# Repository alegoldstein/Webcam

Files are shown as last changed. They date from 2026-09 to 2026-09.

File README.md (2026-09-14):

# Webcam
Objective:
Create a webcam from scratch, including PCB, firmware, and enclosure

Steps Taken:
- Used KiCAD to design a compact 50 mm × 50 mm custom PCB integrating a microcontroller, ESP32 module, camera interface,  input buttons, status LEDs, power regulation circuitry, and passive components.
- Developed embedded firmware in Microchip Studio to enable controlled image capture and system-level communication.
- Implemented multiple communication protocols, including UART and SPI for MCU–ESP32 data exchange and debugging, and  I²C for camera initialization.
- Designed a 3D printed enclosure providing access to buttons and power, visibility for indicator LEDs, and support for wall mounting.

Outcome:
A functional webcam that streams images to the web when there is a connected client.

<p align="center">
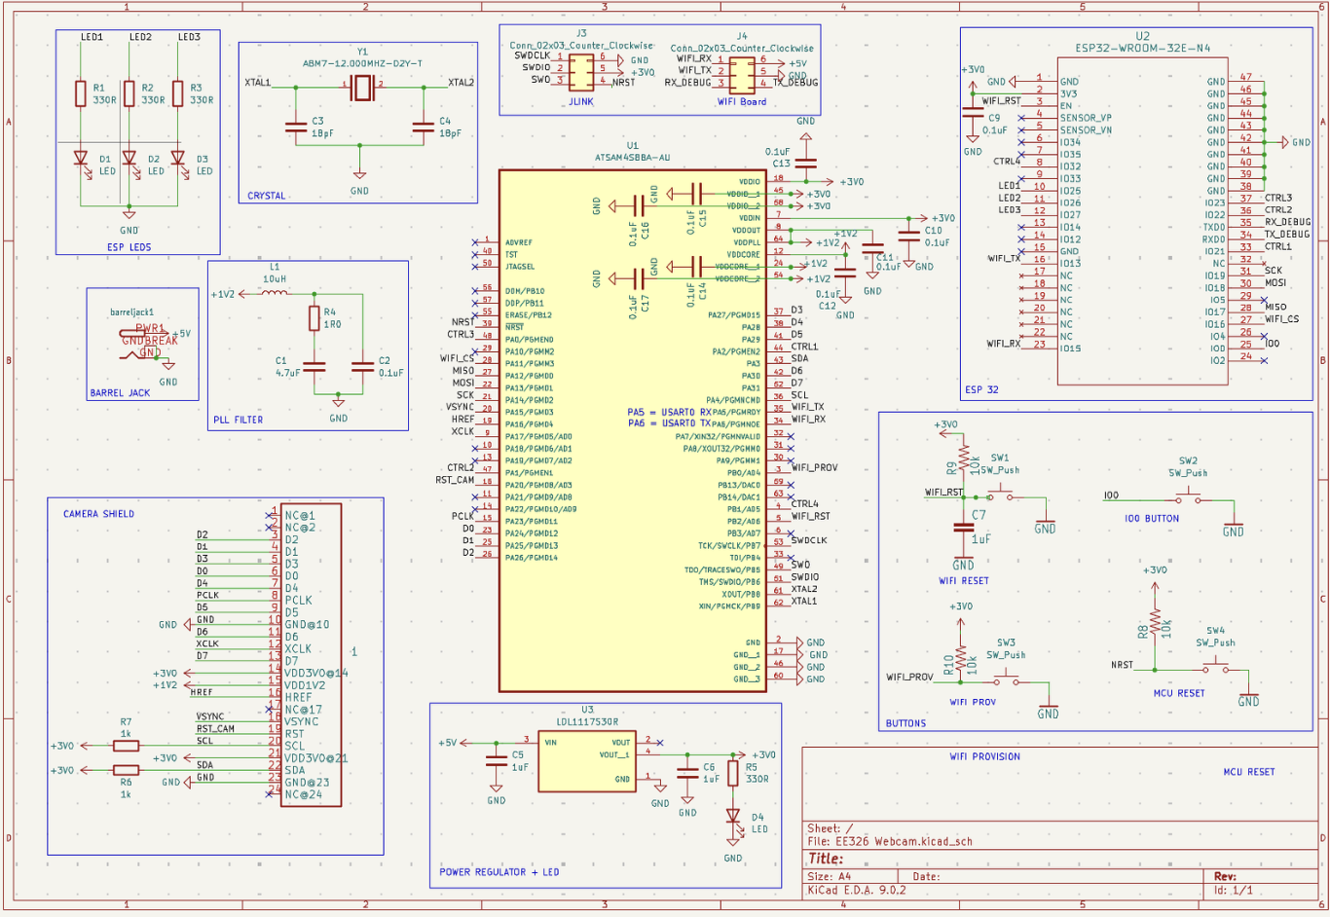
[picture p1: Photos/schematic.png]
  
  <br>
  <em>PCB Schematic</em>
</p>

<p align="center">
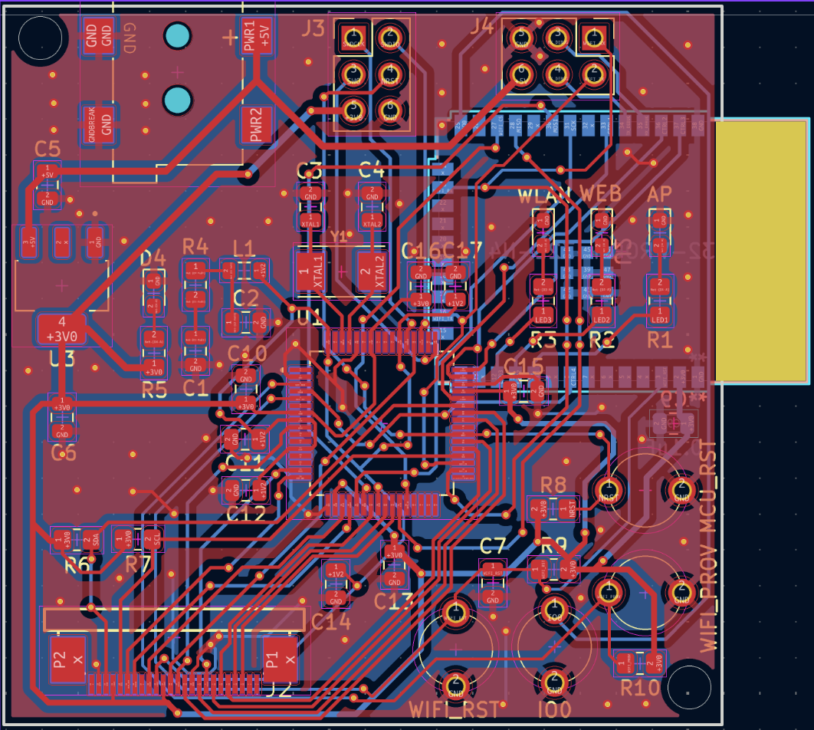
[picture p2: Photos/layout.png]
  
  <br>
  <em>Routing of PCB</em>
</p>

<table align="center">
  <tr>
    <td align="center">
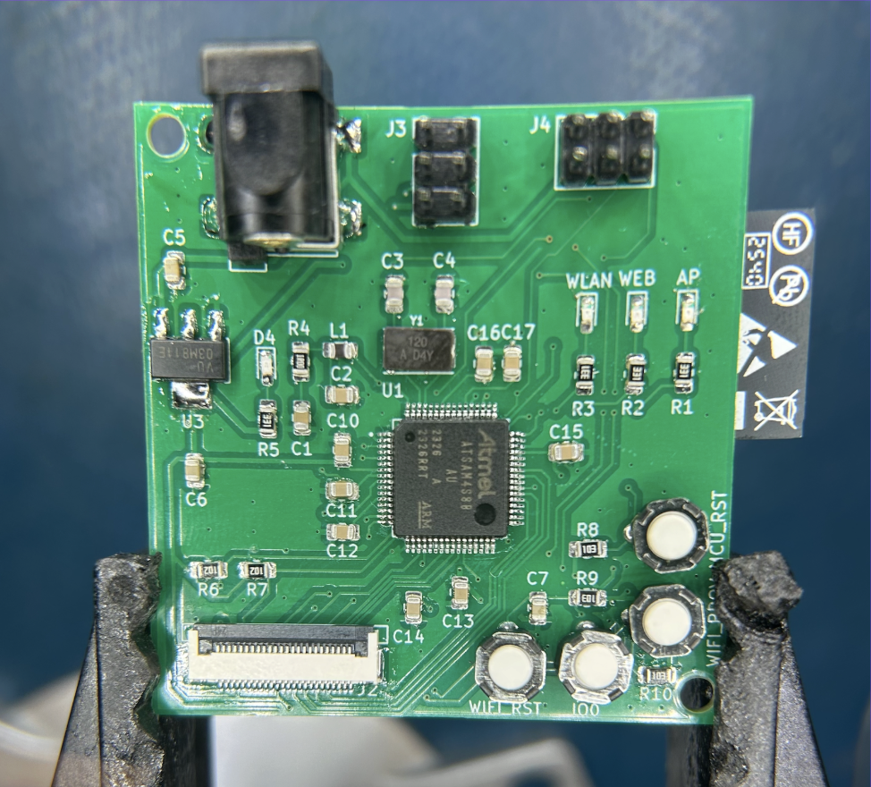
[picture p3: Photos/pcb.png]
      <br>
      <em>Assembled PCB (hand soldered)</em>
    </td>
    <td align="center">
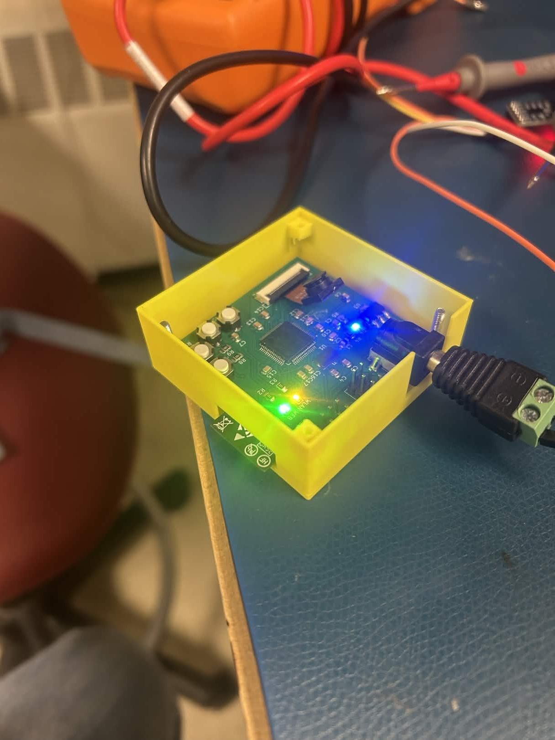
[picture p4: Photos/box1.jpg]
      <br>
      <em>PCB inside of 3D printed box</em>
    </td>
    <td align="center">
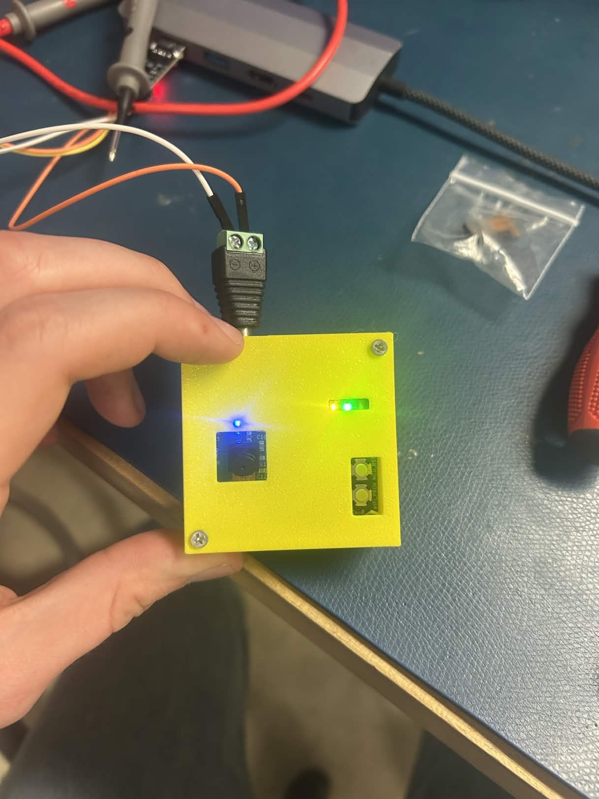
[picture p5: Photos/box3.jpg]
      <br>
      <em>Final product</em>
    </td>
  </tr>
</table>

<p align="center">
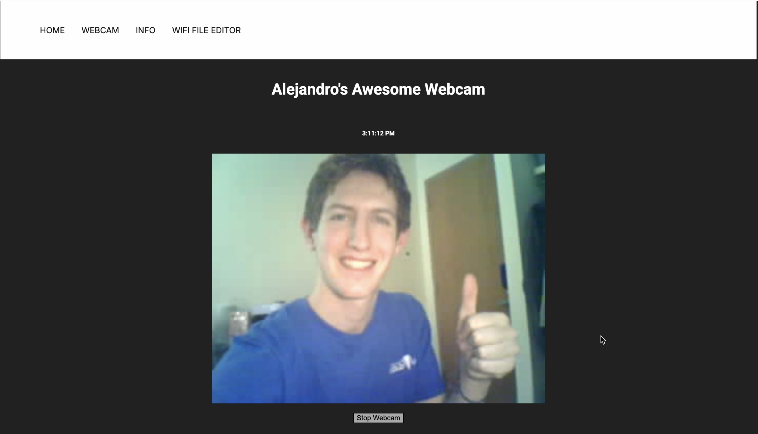
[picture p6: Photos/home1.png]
  
  <br>
  <em>Live streaming of webcam to website</em>
</p>

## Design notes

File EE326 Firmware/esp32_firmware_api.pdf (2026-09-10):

### EE 326: Electronic System Design 1

## WiFi Module API

Firmware version 1.0

This document describes the UART API for the WiFi module firmware. All commands issued must end with a carriage return and a newline character. The Response specification indicates what is returned to the MCU UART, not the debugging UART. The debugging UART may show more information. Any invalid command will get a response of “invalid command” to both the MCU UART and the debugging UART.

## 1 System

- Perform UART test.
– Command: test
– Action: None
– Response: SUCCESS
- Get firmware version.
– Command: ver
– Action: Prints <VERSION NUMBER> to the debugging UART. – Response: None
- Get MAC address of ESP32.
– Command: get mac
– Action: Prints MAC address to debugging UART. – Response: None
- Set SPI baud rate.
– Command: set spi baud <BAUD RATE>
– Action: Set SPI baud rate to <BAUD RATE>.
– Response: None
- Transfer image.
– Command: image transfer <LENGTH IN BYTES>
– Action: Activate controller SPI transfer of <LENGTH IN BYTES> bytes. Make sure the peripheral is ready for transfer.
– Response: None
- Start WiFi provisioning mode on ESP32.
– Command: provision
– Action: Starts provisioning mode on ESP32. This configures the ESP32 as an access point with SSID “ESD1 XY”, where X is the fifth byte of the MAC address and Y is the sixth byte of the MAC address. When you connect to this access point, you will be taken to a captive portal that will allow you to configure your network. When provisioning is complete, the ESP32 will boot into its normal mode of operation.
– Response: None

1

## 2 GPIOs

- Configure network GPIO.
– Command: set net gpio <PIN NUM>
– Action: Set the pin indicated by <PIN NUM> to indicate whether the ESP32 is connected to the internet. If there is a connection, the pin outputs HIGH. Otherwise, it outputs LOW. – Response: None
- Configure websocket clients GPIO.
– Command: set clients gpio <PIN NUM>
– Action: Set the pin indicated by <PIN NUM> to indicate whether any clients are connected to the websockets server hosted by the ESP32, indicating that someone is watching the video stream. If any clients are connected, the pin outputs HIGH. Otherwise, it outputs LOW.
– Response: None
- Configure command complete GPIO.
– Command: set comm gpio <PIN NUM>
– Action: Set the pin indicated by <PIN NUM> to indicate when an API command has finished being received and processed. At the start of processing, this pin goes LOW. When processing is complete, this pin goes HIGH. Therefore, the MCU can sense the rising edge to indicate when it is safe to proceed to the next command.
– Response: None

## 3 Indicators (LEDs)

- Configure network indicator.
– Command: set wlan gpio <PIN NUM>
– Action: Set the pin indicated by <PIN NUM> to indicate the status of the network connection. Short blinks (125ms) indicate no connection. Long blinks (1s) indicate a connection. If <PIN NUM> is specified as “off”, then the indicator is disabled.
– Response: None
- Configure websocket connection indicator.
– Command: set websocket gpio <PIN NUM>
– Action: Set the pin indicated by <PIN NUM> to indicate the status of the websockets connections (i.e. whether clients are connected or not). Short blinks (125ms) indicate no connections. Long blinks (1s) indicate at least one connection. If <PIN NUM> is specified as “off”, then the indicator is disabled.
– Response: None
- Configure provisioning indicator.
– Command: set ap gpio <PIN NUM>
– Action: Set the pin indicated by <PIN NUM> to indicate the status of provisioning mode. Short blinks (125ms) indicate that provisioning mode is active but no clients have connected to the access point. Long blinks (1s) indicate that provisioning mode is active an a client has connected to the access point. When provisioning is complete, the indicator turns off. If <PIN NUM> is specified as “off”, then the indicator is disabled.
– Response: None

2

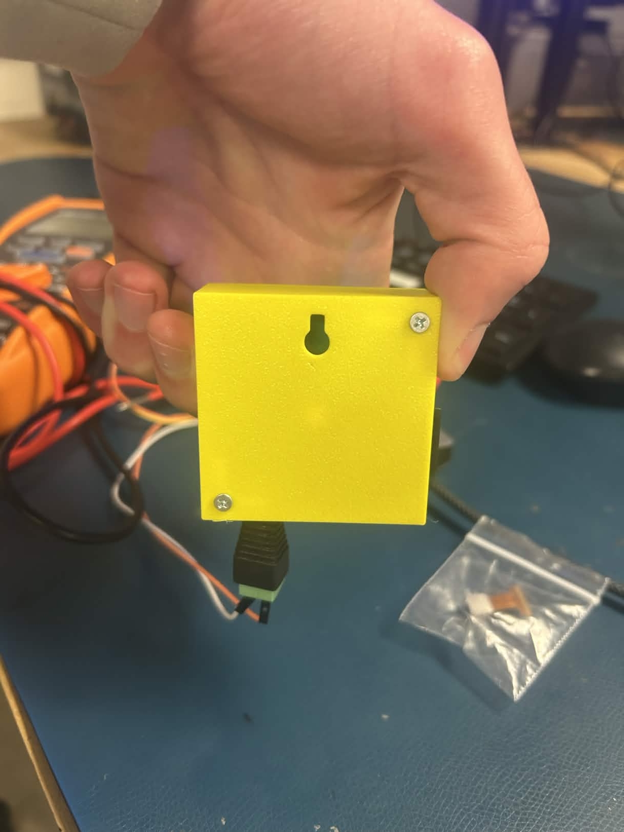
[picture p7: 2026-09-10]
Photos/box2.jpg

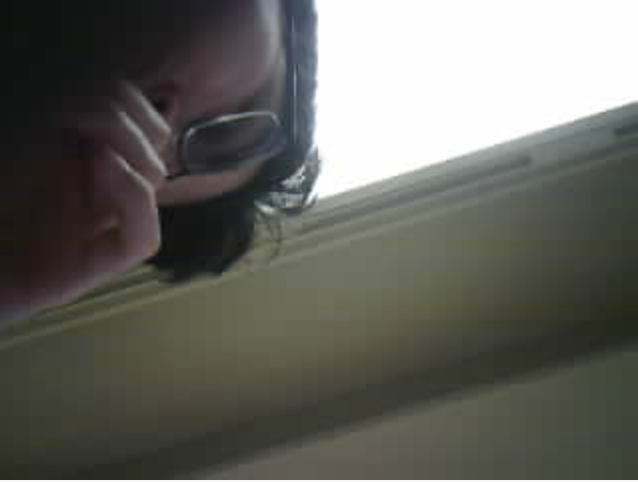
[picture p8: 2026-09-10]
Photos/Screenshot 2026-03-10 at 5.40.54 PM.png

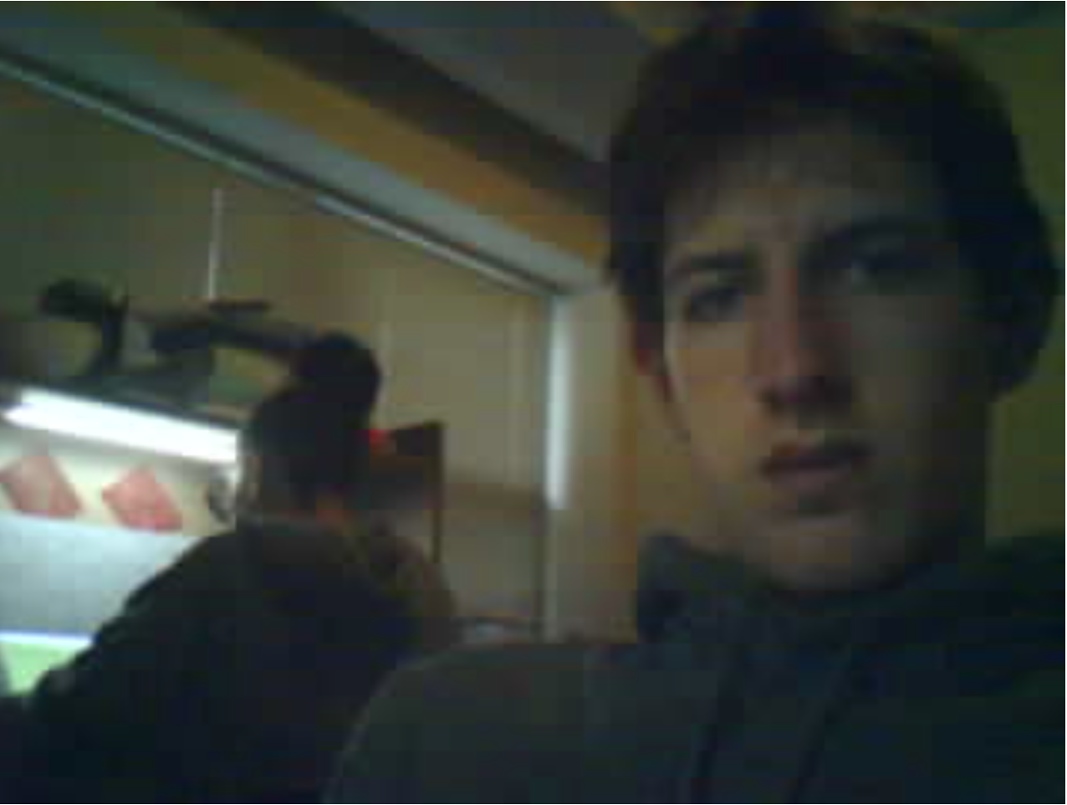
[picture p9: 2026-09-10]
Photos/Screenshot 2026-03-17 at 6.42.02 PM.png

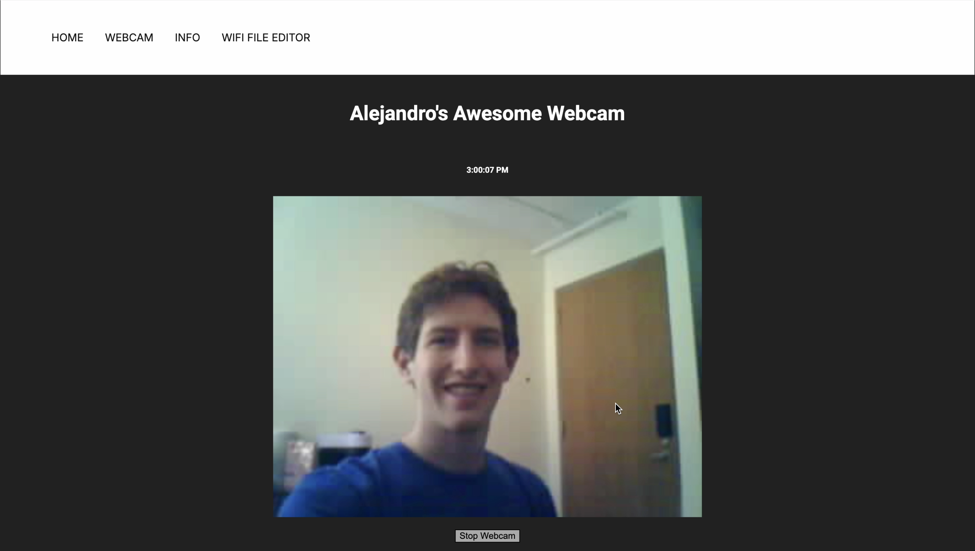
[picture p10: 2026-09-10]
Photos/Screenshot 2026-03-20 at 3.03.37 PM.png

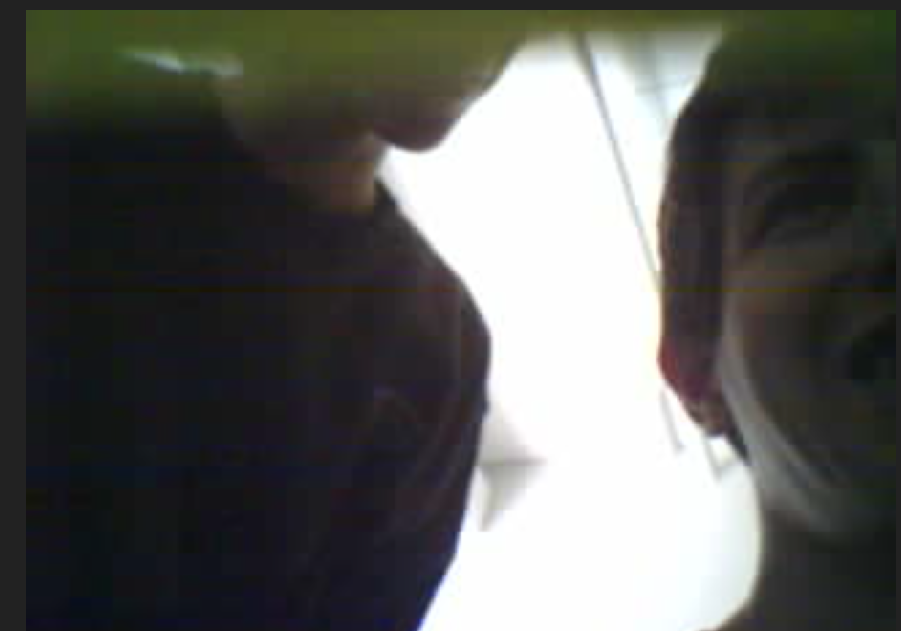
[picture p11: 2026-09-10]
Photos/Screenshot 2026-03-20 at 1.47.19 PM.png

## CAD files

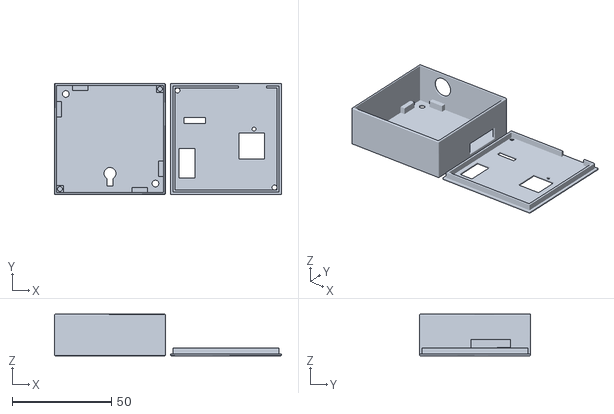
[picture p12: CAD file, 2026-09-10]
3D Models/ee326_boxv4.stl
114.6 x 56.0 x 21.0

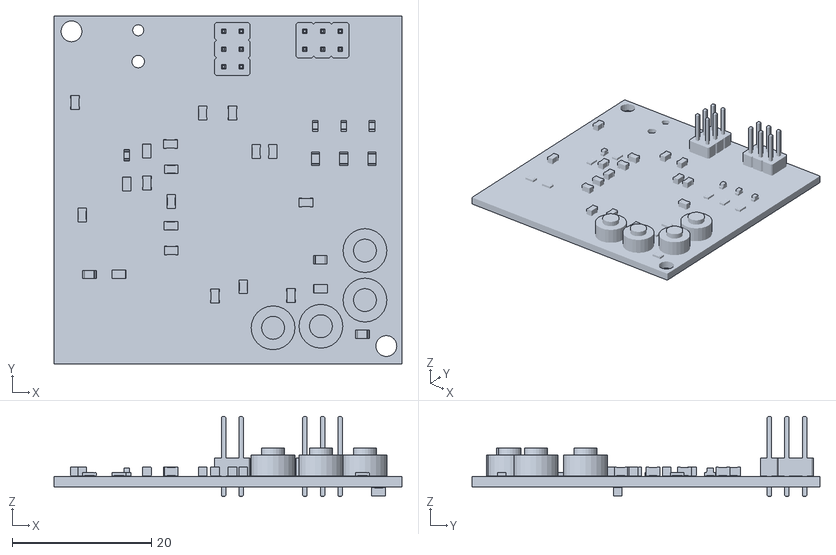
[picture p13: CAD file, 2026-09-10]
PCB/EE326 Webcam.stl
50.0 x 50.0 x 11.5

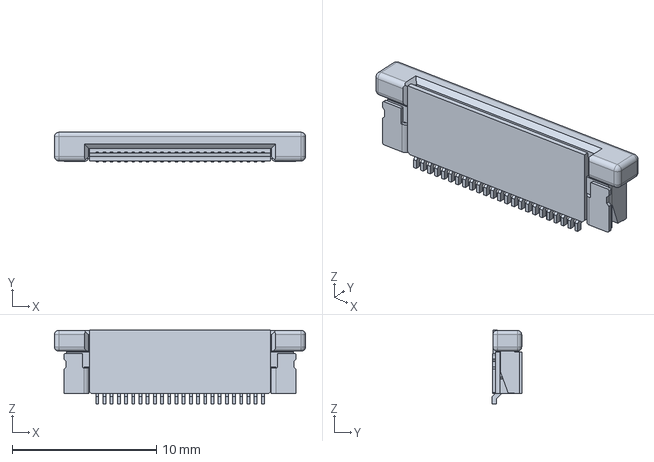
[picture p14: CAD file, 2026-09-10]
PCB/Symbols+Footprints/2_1734592_4/2-1734592-4.step
17.4 x 2.05 x 5.11 mm

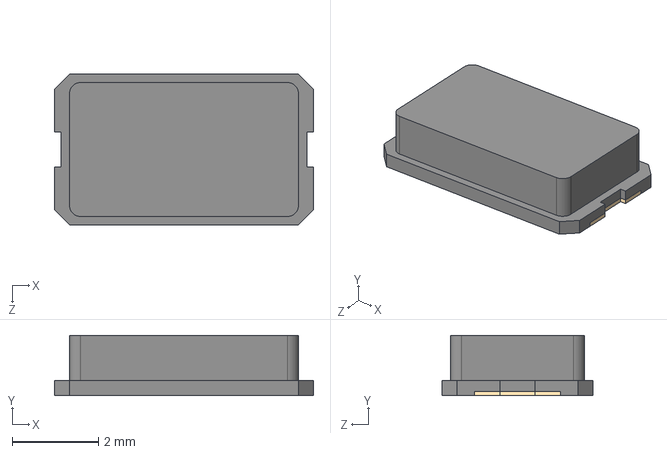
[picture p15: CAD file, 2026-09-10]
PCB/Symbols+Footprints/ABM7_12_000MHZ_D2Y_T/ABM7-12.000MHZ-D2Y-T.step
6.00 x 1.40 x 3.50 mm

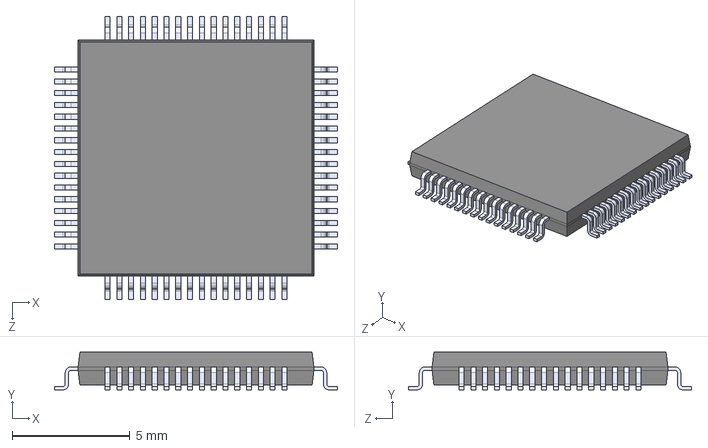
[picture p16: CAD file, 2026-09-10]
PCB/Symbols+Footprints/ATSAM4S8BA_AU/ATSAM4S8BA-AU.step
12.0 x 1.60 x 12.0 mm

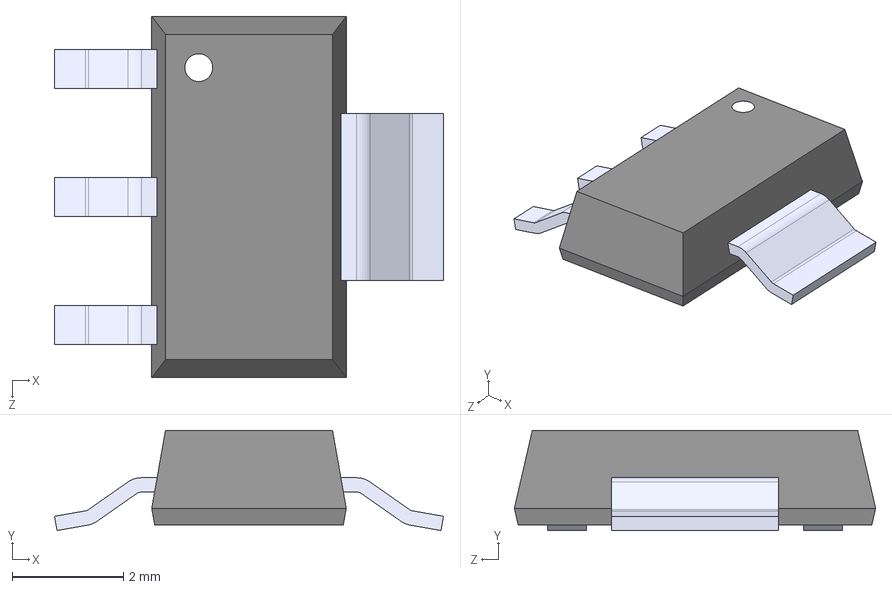
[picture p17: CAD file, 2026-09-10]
PCB/Symbols+Footprints/LDL1117S30R/LDL1117S30R.step
7.00 x 1.80 x 6.50 mm

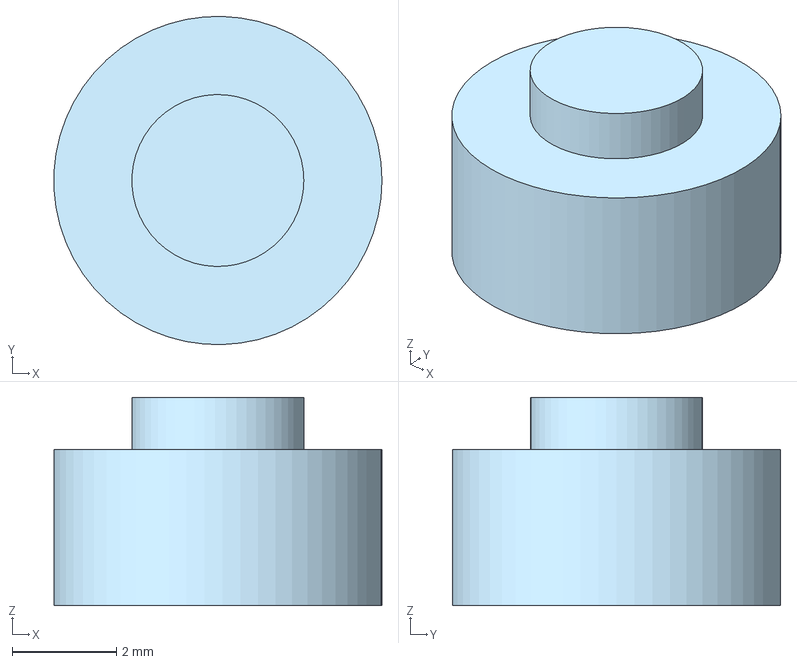
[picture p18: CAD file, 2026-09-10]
PCB/Symbols+Footprints/pushbutton.step
6.30 x 6.30 x 4.00 mm

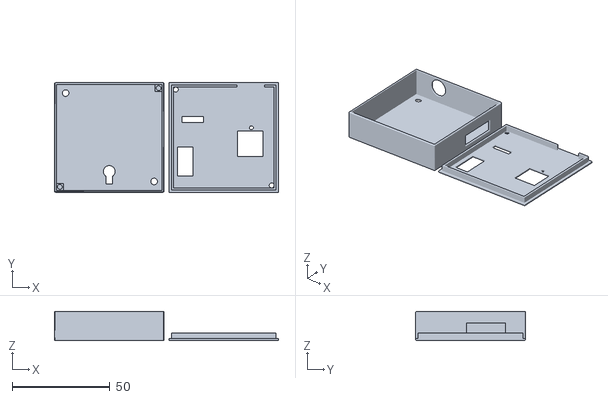
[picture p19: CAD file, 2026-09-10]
3D Models/ee326_boxv3.stl
114.6 x 56.0 x 15.0

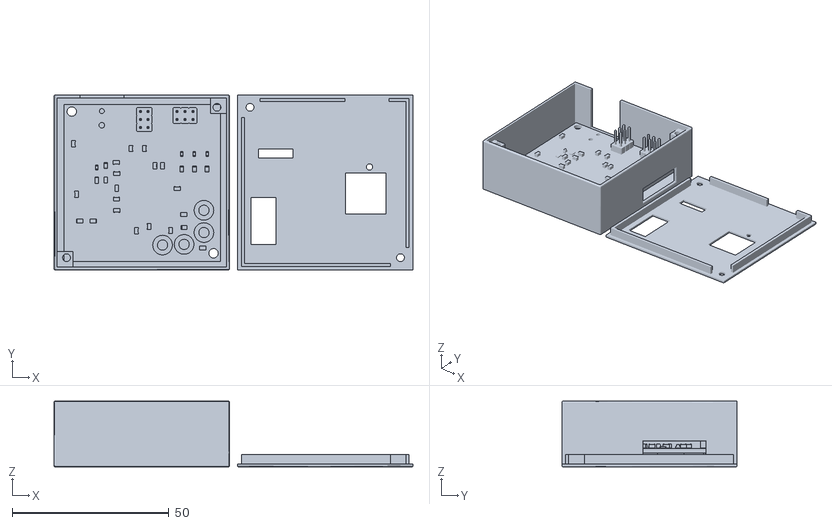
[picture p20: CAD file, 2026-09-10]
3D Models/ee326_box_final.stl
114.6 x 56.0 x 21.0

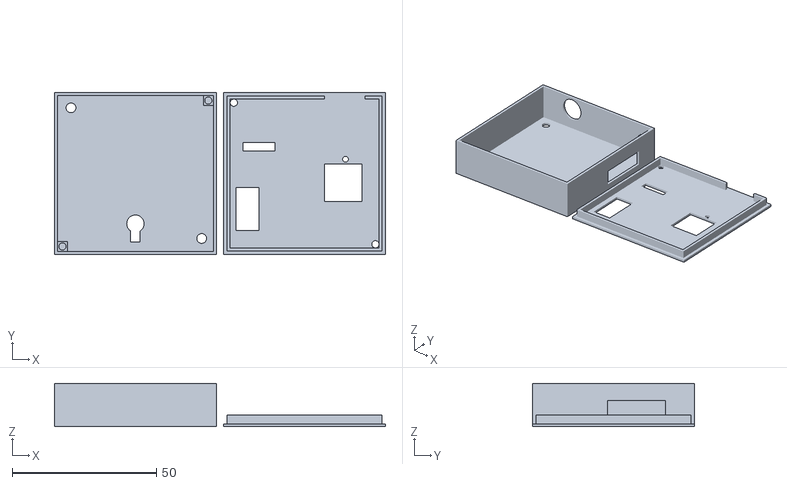
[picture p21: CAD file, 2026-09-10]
3D Models/EE326_box_v2.stl
114.6 x 56.0 x 15.0

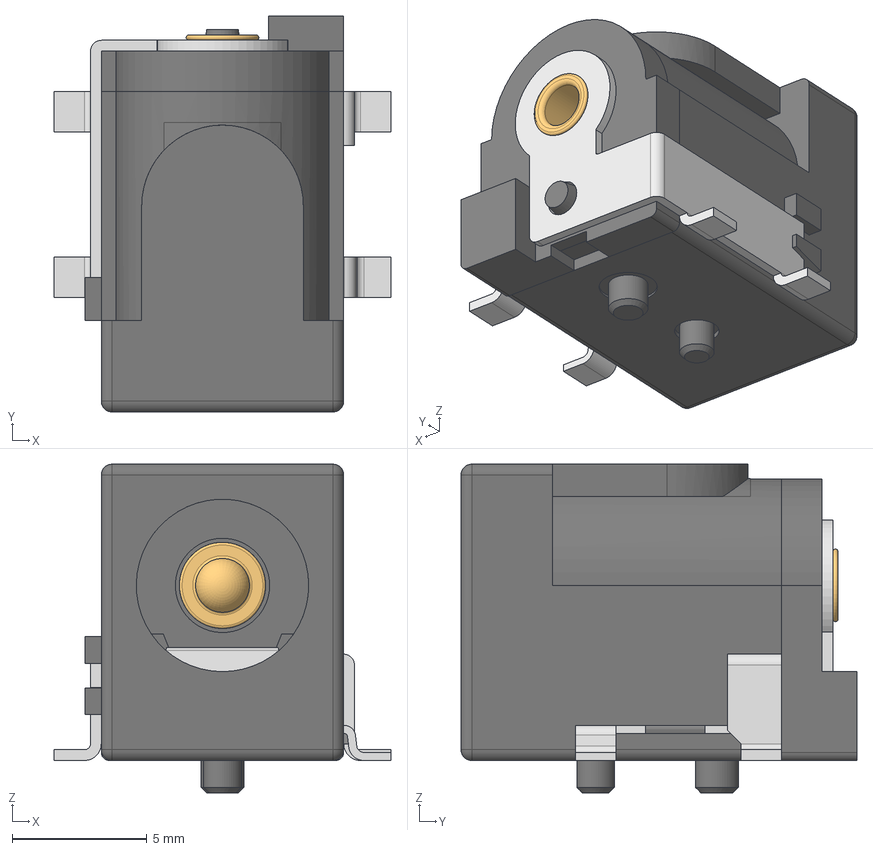
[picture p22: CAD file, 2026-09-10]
PCB/Symbols+Footprints/694106106102/694106106102.step
12.5 x 14.7 x 12.2 mm
6941xx106102
6941xx106102_Capot
694106301002_PinContact
6941xx106102_PIN
6941xx106102_PINBIS
6941xx106102_PINLAME

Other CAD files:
3D Models/ee326_boxv6.stl
3D Models/ee326_boxv5.stl
3D Models/ee326_box_v1.3mf.gcode.3mf
3D Models/ee326_boxv1.gcode.3mf
PCB/Symbols+Footprints/694106106102+%28rev1%29.stp
3D Models/EE326_box_v1.stl

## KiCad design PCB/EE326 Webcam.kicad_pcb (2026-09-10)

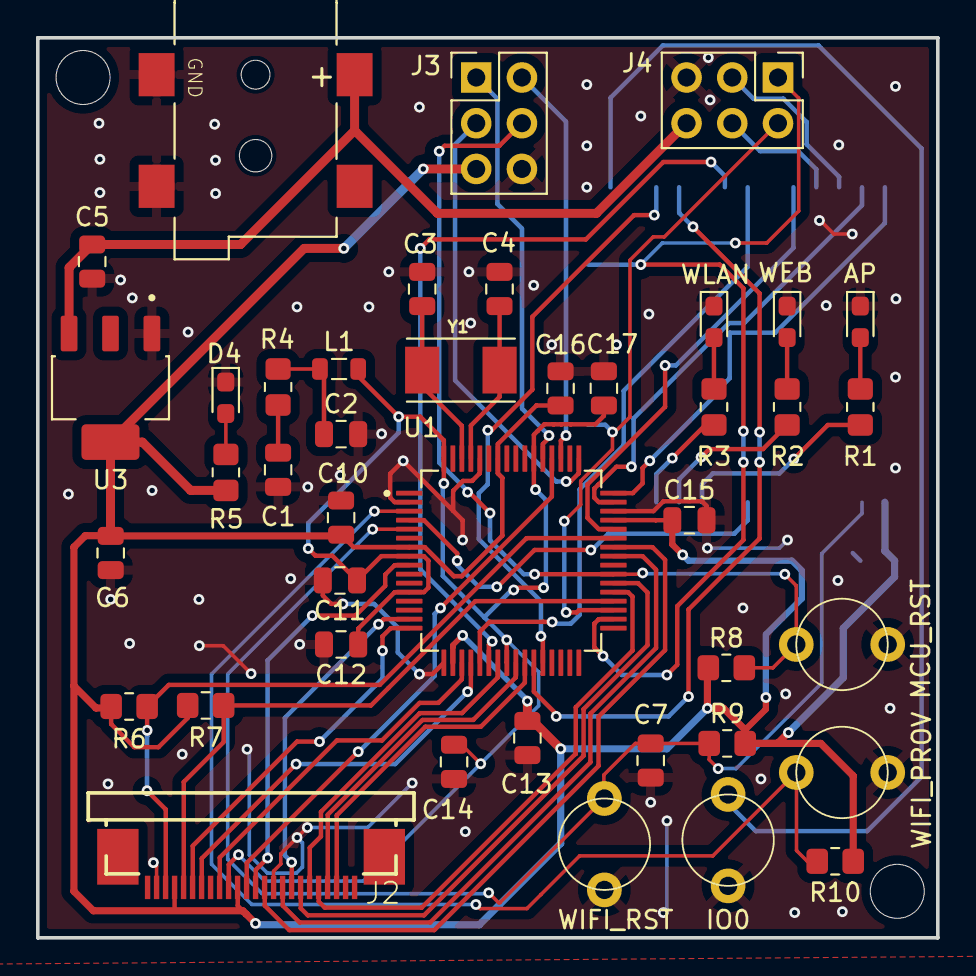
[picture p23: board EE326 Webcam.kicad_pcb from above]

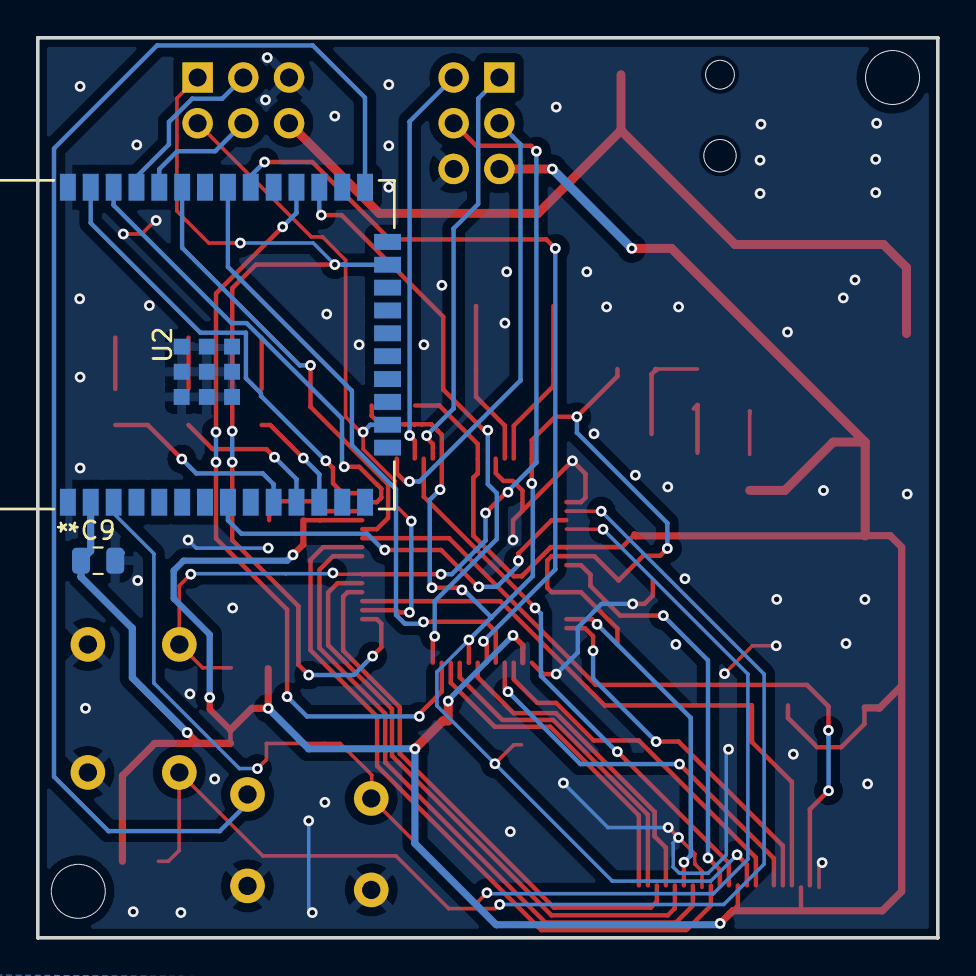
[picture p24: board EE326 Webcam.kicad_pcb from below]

Board: 2 copper layers, 50.0 x 50.0 mm, 43 parts (2 on the bottom side), 49 nets.

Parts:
AP: LED; LED_0603_1608Metric_Pad1.05x0.95mm_HandSolder
C1: 4.7uF; C_0805_2012Metric
C2, C9, C10, C11, C12, C13, C14, C15, C16, C17: 0.1uF; C_0805_2012Metric
C3, C4: 18pF; C_0805_2012Metric
C5, C6, C7: 1uF; C_0805_2012Metric
D4: LED; LED_0603_1608Metric_Pad1.05x0.95mm_HandSolder
IO0: SW_Push; pushbutton
J2: 2-1734592-4; CAM_CONN
J3, J4: Conn_02x03_Counter_Clockwise; PinHeader_2x03_P2.54mm_Vertical
L1: 10uH; L_0805_2012Metric
MCU_RST: SW_Push; pushbutton
R1, R2, R3, R5: 330R; R_0805_2012Metric_Pad1.20x1.40mm_HandSolder
R4: 1R0; R_0805_2012Metric_Pad1.20x1.40mm_HandSolder
R6, R7: 1k; R_0805_2012Metric_Pad1.20x1.40mm_HandSolder
R8, R9, R10: 10k; R_0805_2012Metric_Pad1.20x1.40mm_HandSolder
U1: ATSAM4S8BA-AU; atsam4s8b
U2: ESP32-WROOM-32E-N4; ESP32­WROOM­32E_EXP
U3: LDL1117S30R; voltage regulator
WEB: LED; LED_0603_1608Metric_Pad1.05x0.95mm_HandSolder
WIFI_PROV: SW_Push; pushbutton
WIFI_RST  : SW_Push; pushbutton
WLAN: LED; LED_0603_1608Metric_Pad1.05x0.95mm_HandSolder
Y1: ABM7-12.000MHZ-D2Y-T; crystal clock
barreljack1: DCJACK_2MM_SMT

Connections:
+1V2: C11.1, C12.1, C14.1, C17.1, J2.15, L1.1, U1.8 (VDDOUT), U1.12 (VDDCORE), U1.24 (VDDCORE__1), U1.54 (VDDCORE__2), U1.64 (VDDPLL)
+3V0: C6.1, C9.1, C10.1, C13.1, C15.1, C16.1, J2.14, J2.21, J3.5, R5.1, R6.1, R7.1, R8.2, R9.2, R10.2, U1.7 (VDDIN), U1.18 (VDDIO), U1.45 (VDDIO__1), U1.58 (VDDIO__2), U2.2 (3V3), U3.4 (VOUT__1)
+5V: C5.1, J4.6, U3.3 (VIN), barreljack1.PWR1 (PWR)
/CTRL1: U1.44 (PA2/PGMEN2), U2.33 (IO21)
/CTRL2: U1.47 (PA1/PGMEN1), U2.36 (IO22)
/CTRL3: U1.48 (PA0/PGMEN0), U2.37 (IO23)
/CTRL4: U1.4 (PB1/AD5), U2.8 (IO32)
/D0: J2.6, U1.23 (PA24/PGMD12)
/D1: J2.4, U1.25 (PA25/PGMD13)
/D2: J2.3, U1.26 (PA26/PGMD14)
/D3: J2.5, U1.37 (PA27/PGMD15)
/D4: J2.7, U1.38 (PA28)
/D5: J2.9, U1.41 (PA29)
/D6: J2.11, U1.42 (PA30)
/D7: J2.13, U1.52 (PA31)
/HREF: J2.16, U1.19 (PA16/PGMD4)
/IO0: IO0.1, U2.25 (IO0)
/LED1: R1.1, U2.10 (IO25)
/LED2: R2.1, U2.11 (IO26)
/LED3: R3.1, U2.12 (IO27)
/MISO: U1.27 (PA12/PGMD0), U2.28 (IO17)
/MOSI: U1.22 (PA13/PGMD1), U2.30 (IO18)
/NRST: J3.4, MCU_RST.1, R8.1, U1.39 (~NRST)
/PCLK: J2.8, U1.15 (PA23/PGMD11)
/RST_CAM: J2.19, U1.16 (PA20/PGMD8/AD3)
/RX_DEBUG: J4.3, U2.35 (TXD0)
/SCK: U1.21 (PA14/PGMD2), U2.31 (IO19)
/SCL: J2.20, R7.2, U1.36 (PA4/PGMNCMD)
/SDA: J2.22, R6.2, U1.43 (PA3)
/SWDCLK: J3.1, U1.53 (TCK/SWCLK/PB7)
/SWDIO: J3.2, U1.51 (TMS/SWDIO/PB6)
/SWO: J3.3, U1.49 (TDO/TRACESWO/PB5)
/TX_DEBUG: J4.4, U2.34 (RXD0)
/VSYNC: J2.18, U1.20 (PA15/PGMD3)
/WIFI_CS: U1.28 (PA11/PGMM3), U2.27 (IO16)
/WIFI_PROV: R10.1, U1.3 (PB0/AD4), WIFI_PROV.1
/WIFI_RST: C7.1, R9.1, U1.5 (PB2/AD6), U2.3 (EN), WIFI_RST.1
/WIFI_RX: J4.1, U1.34 (PA6/PGMNOE), U2.23 (IO15)
/WIFI_TX: J4.2, U1.35 (PA5/PGMRDY), U2.16 (IO13)
/XCLK: J2.12, U1.9 (PA17/PGMD5/AD0)
/XTAL1: C3.1, U1.62 (XIN/PGMCK/PB9), Y1.1
/XTAL2: C4.1, U1.61 (XOUT/PB8), Y1.2
GND: AP.1 (K), C1.2, C2.2, C3.2, C4.2, C5.2, C6.2, C7.2, C9.2, C10.2, C11.2, C12.2, C13.2, C14.2, C15.2, C16.2, C17.2, D4.1 (K), IO0.2, J2.10, J2.23, J3.6, J4.5, MCU_RST.2, U1.2 (GND), U1.17 (GND__1), U1.46 (GND__2), U1.60 (GND__3), U2.1 (GND), U2.38 (GND), U2.39 (GND), U2.40 (GND), U2.41 (GND), U2.42 (GND), U2.43 (GND), U2.44 (GND), U2.45 (GND), U2.46 (GND), U2.47 (GND), U3.1 (GND), WEB.1 (K), WIFI_PROV.2, WIFI_RST.2, WLAN.1 (K), barreljack1.GND, barreljack1.GNDBREAK
unnamed: C1.1, R4.2
unnamed: C2.1, L1.2, R4.1
unnamed: AP.2 (A), R1.2
unnamed: R2.2, WEB.2 (A)
unnamed: R3.2, WLAN.2 (A)
unnamed: D4.2 (A), R5.2

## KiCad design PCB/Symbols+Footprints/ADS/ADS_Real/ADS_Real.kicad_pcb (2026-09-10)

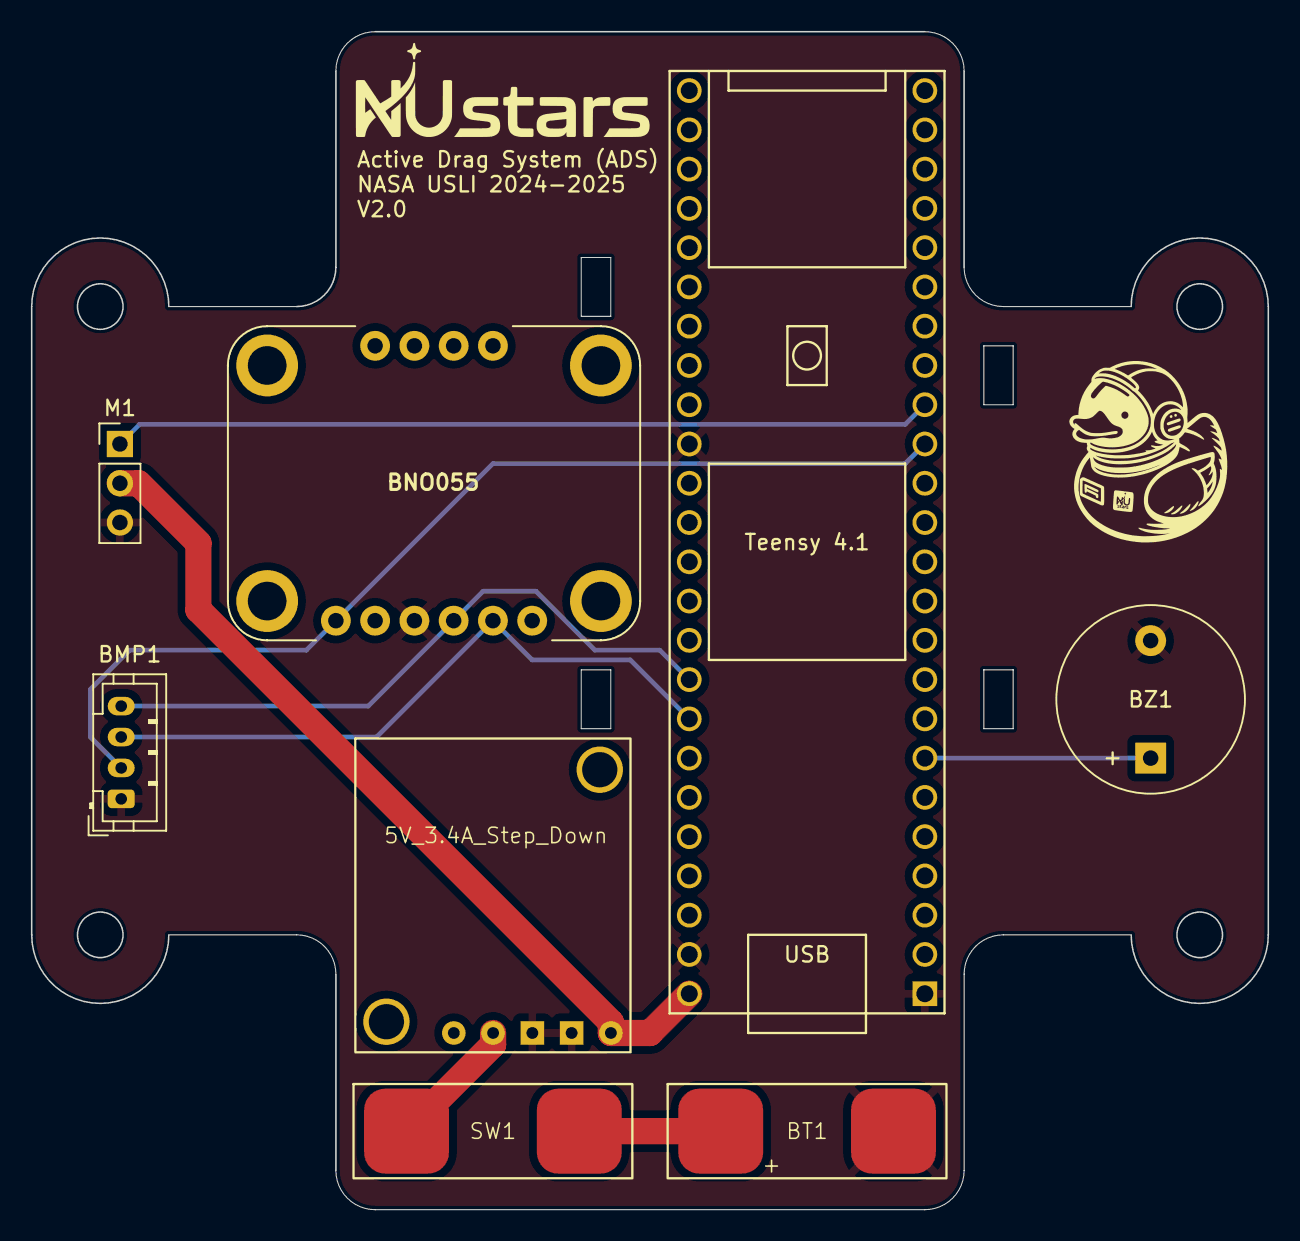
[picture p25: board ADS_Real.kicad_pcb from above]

Board: 2 copper layers, 80.0 x 76.2 mm, 8 parts (0 on the bottom side), 9 nets.

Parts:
5V_3.4A_Step_Down1: 5V_3.4A_Step_Down
BMP1: JST_PH_B4B-PH-K_1x04_P2.00mm_Vertical
BT1: LiPo; SolderPad_5.5mm_2Pads_Directional
BZ1: Buzzer; Buzzer_12x9.5RM7.6
M1: Motor_Servo; PinHeader_1x03_P2.54mm_Vertical
SW1: Pull_Pin; SolderPad_5.5mm_2Pads_Bidirectional
Teensy 4.1: Teensy4.1; Teensy41
U2: BNO055

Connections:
+7.4V: BT1.1 (+), SW1.2 (B)
/Buzzer_In: BZ1.1 (+), Teensy 4.1.7 (5_IN2)
/Pull_Pin_Input: 5V_3.4A_Step_Down1.2 (VIN), SW1.3 (C)
/Pull_Pin_Output: 5V_3.4A_Step_Down1.5 (VOUT), M1.2 (+), Teensy 4.1.48 (VIN)
/SCL: BMP1.3 (SCL), Teensy 4.1.41 (19_A5_SCL), U2.5 (SCL)
/SDA: BMP1.4 (SDA), Teensy 4.1.40 (18_A4_SDA), U2.4 (SDA)
/Sensor_VIN: BMP1.2 (VIN), Teensy 4.1.15 (3V3), U2.1 (VIN)
/Servo_Signal: M1.1 (PWM), Teensy 4.1.16 (24_A10_TX6_SCL2)
GND: 5V_3.4A_Step_Down1.3 (GND), 5V_3.4A_Step_Down1.4 (GND), BMP1.1 (GND), BT1.2 (-), BZ1.2 (-), M1.3 (-), Teensy 4.1.1 (GND), Teensy 4.1.34 (GND), Teensy 4.1.47 (GND), U2.3 (GND)

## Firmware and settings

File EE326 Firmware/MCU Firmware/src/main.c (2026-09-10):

#include <asf.h>
#include "wifi.h"
#include "camera.h"
#include "init.h"
#include "timer_interface.h"

/* int main(void)
{
    // system init
    sysclk_init();
    board_init();
    init_board_pins();
    configure_tc();

    // wifi init
    configure_usart_wifi();             // fixed name
    configure_spi();
    spi_peripheral_initialize();
    configure_wifi_comm_pin();
    configure_wifi_provision_pin();

    // camera init
    init_vsync_interrupts();
    init_camera();
    configure_camera();

    // reset ESP first so it's running before we send commands
    gpio_set_pin_low(WIFI_RST_PIN);
    delay_ms(100);
    gpio_set_pin_high(WIFI_RST_PIN);
    delay_ms(500);                      // wait for ESP to boot

    // configure ESP32 GPIOs
	usart_write_line(WIFI_USART, "set comm_gpio 21\r\n");


    char cmd_buf[50];
    sprintf(cmd_buf, "set wlan_gpio 27\r\n");
    write_wifi_command(cmd_buf, 10);

    sprintf(cmd_buf, "set websocket_gpio 26\r\n");
    write_wifi_command(cmd_buf, 10);

    sprintf(cmd_buf, "set ap_gpio 25\r\n");
    write_wifi_command(cmd_buf, 10);

    sprintf(cmd_buf, "set comm_pin 21\r\n");
    write_wifi_command(cmd_buf, 10);

    sprintf(cmd_buf, "set net_pin 22\r\n");
    write_wifi_command(cmd_buf, 10);

    sprintf(cmd_buf, "set clients_pin 32\r\n");
    write_wifi_command(cmd_buf, 10);

    // wait for network connection, handle provisioning while waiting
    while (!ioport_get_pin_level(WIFI_NET_PIN)) {
        if (WIFI_PROVISION_FLAG) {
            WIFI_PROVISION_FLAG = 0;
            sprintf(cmd_buf, "provision\r\n");
            write_wifi_command(cmd_buf, 10);
        }
    }

    // send test, retry every 10 seconds until SUCCESS
    wifi_comm_success = false;
    counts = 0;
    usart_write_line(WIFI_USART, "test\r\n");

    while (!wifi_comm_success) {
        if (counts >= 10) {
            counts = 0;
            gpio_set_pin_low(WIFI_RST_PIN);
            delay_ms(100);
            gpio_set_pin_high(WIFI_RST_PIN);
            delay_ms(500);
            while (!ioport_get_pin_level(WIFI_NET_PIN)) {}
            sprintf(cmd_buf, "test\r\n");
            write_wifi_command(cmd_buf, 10);
        }
    }
    wifi_comm_success = false;

    // main loop
    while (1) {

        // check for provisioning request
        if (WIFI_PROVISION_FLAG) {
            WIFI_PROVISION_FLAG = 0;
            sprintf(cmd_buf, "provision\r\n");
            write_wifi_command(cmd_buf, 10);
            while (!ioport_get_pin_level(WIFI_NET_PIN)) {}
        }

        // capture and send if network up and clients connected
        if (ioport_get_pin_level(WIFI_NET_PIN) && ioport_get_pin_level(WIFI_CLIENTS_PIN)) {
            if (start_capture()) {
                write_image_to_web();
            }
        }
    }
}
	*/

int main(void){
	sysclk_init();
	//wdt_disable(WDT);
	board_init();
	
	configure_usart_wifi();
	configure_wifi_comm_pin();
	usart_write_line(WIFI_USART, "set comm_gpio 21\r\n");

	while(1) {
		usart_write_line(WIFI_USART, "test\r\n");
		delay_ms(500);
	}
}

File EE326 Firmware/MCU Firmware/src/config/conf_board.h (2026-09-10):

#ifndef conf_board_h
#define conf_board_h

#define PINS_WIFI_USART				(PIO_PA5A_RXD0 | PIO_PA6A_TXD0)
#define PINS_WIFI_USART_FLAGS		(PIO_PERIPH_A | PIO_DEFAULT)
#define PINS_WIFI_USART_MASK		(PIO_PA5A_RXD0 | PIO_PA6A_TXD0)
#define PINS_WIFI_USART_PIO			PIOA
#define PINS_WIFI_USART_ID			ID_PIOA
#define PINS_WIFI_USART_TYPE		PIO_PERIPH_A
#define PINS_WIFI_USART_ATTR		PIO_DEFAULT

/** USART0 pin RX */
#define PIN_USART0_RXD	  {PIO_PA5A_RXD0, PIOA, ID_PIOA, PIO_PERIPH_A, PIO_PULLUP}
#define PIN_USART0_RXD_IDX        (PIO_PA5_IDX)
#define PIN_USART0_RXD_FLAGS      (PIO_PERIPH_A | PIO_PULLUP)
/** USART0 pin TX */
#define PIN_USART0_TXD    {PIO_PA6A_TXD0, PIOA, ID_PIOA, PIO_PERIPH_A, PIO_PULLUP}
#define PIN_USART0_TXD_IDX        (PIO_PA6_IDX)
#define PIN_USART0_TXD_FLAGS      (PIO_PERIPH_A | PIO_PULLUP)

/** SPI MISO pin definition. */
#define SPI_MISO_GPIO         (PIO_PA12_IDX)
#define SPI_MISO_FLAGS       (PIO_PERIPH_A | PIO_DEFAULT)
/** SPI MOSI pin definition. */
#define SPI_MOSI_GPIO         (PIO_PA13_IDX)
#define SPI_MOSI_FLAGS       (PIO_PERIPH_A | PIO_DEFAULT)
/** SPI SPCK pin definition. */
#define SPI_SPCK_GPIO         (PIO_PA14_IDX)
#define SPI_SPCK_FLAGS       (PIO_PERIPH_A | PIO_DEFAULT)

/** SPI chip select 0 pin definition. (Only one configuration is possible) */
#define SPI_NPCS0_GPIO         (PIO_PA11_IDX)
#define SPI_NPCS0_FLAGS           (PIO_PERIPH_A | PIO_DEFAULT)



//cam pin declarations
#define PIN_D0     (PIO_PA25_IDX)
#define PIN_D1     (PIO_PA24_IDX)
#define PIN_D2     (PIO_PA26_IDX)
#define PIN_D3     (PIO_PA27_IDX)
#define PIN_D4     (PIO_PA28_IDX)
#define PIN_D5     (PIO_PA29_IDX)
#define PIN_D6     (PIO_PA30_IDX)
#define PIN_D7     (PIO_PA31_IDX)

#define PIN_CAM_SCL     (PIO_PA4_IDX)
#define PIN_CAM_SDA     (PIO_PA3_IDX)
#define PIN_CAM_XCLK     (PIO_PA17_IDX)
#define PIN_CAM_PCLK     (PIO_PA23_IDX)
#define PIN_HREF     (PIO_PA16_IDX)
#define PIN_VSYNC     (PIO_PA15_IDX)
#define PIN_CAM_RST     (PIO_PA20_IDX)

#define OV2640_DATA_BUS_PIO     PIOA
#define OV2640_DATA_BUS_ID      ID_PIOA

#define PIN_VSYNC_PIO           PIOA
#define OV2640_VSYNC_ID         ID_PIOA
#define OV2640_VSYNC_MASK       (1 << 15)   // PA15



#define CONSOLE_UART_ID ID_UART0

#define CONF_BOARD_SPI

#define CONF_BOARD_SPI_NPCS0

//peripheral ID definitions
#define SPI_ID ID_SPI

//base addresses
#define SPI_MASTER_BASE
#define SPI_SLAVE_BASE

#endif

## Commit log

2026-09-10 move files
    [2-1734592-4.step, 694106106102+%28rev1%29.stp, 694106106102.step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]
2026-09-10 Fix HTML tags in README.md for PCB images
